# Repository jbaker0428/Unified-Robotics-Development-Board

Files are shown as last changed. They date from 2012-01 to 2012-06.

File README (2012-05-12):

The Unified Robotics Development Board seeks to provide an extensible open-hardware platform for robotics development based on XMOS technology.

SOFTWARE USED:
PCB design: Eagle 5.6.0
STM32 code: Eclipse Indigo SR1 (CDT) and YAGARTO (Yet another GNU ARM toolchain)
XMOS code: XMOS Development Environment

The Unified Robotics Development Board is licensed under a Creative Commons Attribution-NonCommercial-ShareAlike 3.0 Unported License.

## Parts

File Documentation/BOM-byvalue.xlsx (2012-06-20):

Part | Value | Device | Package | Vendor | Vendor PN | Manufacturer PN | Qty | Unit Price @ Qty | Part Price | TOTAL: | Notes
BAT1 |  | CBC3112 | D7C-VFN20 | DK | 859-1010-1-ND | CBC3112-D7C-TR1 | 1 | 2.91 | 2.91 | 191.4278
C1, C76, C102, C103 | 1uF | C-US0402 | C0402 | DK | 445-4979-1-ND | C1005X5R1C105M | 4 | 0.27 | 1.08
C2, C9, C10, C17, C29, C35, C74, C75, C92, C98, C99, C105, C106 | 10uF | C-USC0805 | C0805 | DK | 490-5523-1-ND | GRM21BR61E106KA73L | 13 | 0.231 | 3.003
C3, C4, C11, C12, C13, C14, C21, C22, C23, C25, C28, C30, C33, C38, C39, C40, C41, C42, C45, C46, C47. C49, C55, C56, C86, C87, C88, C89 | 0.1uF | C-USC0603 | C0603 | DK | 311-1343-1-ND | CC0603ZRY5V9BB104 | 29 | 0.017 | 0.493
C5, C6 | 18pF | C-USC0603 | C0603 |  |  |  | 2 |  | 0
C7 | 290pF | C-USC0603 | C0603 | DK | 445-5066-1-ND | C1608C0G1H301J | 1 | 0.12 | 0.12 |  | Real part value is 300pF
C8 | 100uF | C-USC0805 | C0805 |  |  |  | 1 |  | 0 |  | TODO: Make this a 1206
C15, C52 | 22uF | CAP_ | AXIAL-5MM | DK | 445-2904-ND | FK22Y5V1E226Z | 2 | 1.4 | 2.8
C16 | 4.7uF | CAP_ | AXIAL-5MM | DK | 445-2880-ND | FK26Y5V1E475Z | 1 | 0.43 | 0.43
C18 | 0.01uF | C-USC0603 | C0603 | DK | 478-1227-1-ND | 06035C103KAT2A | 1 | 0.06 | 0.06 |  | 0.01uF = 10k pF
C19, C24 | 4.7uF | C-USC0805 | C0805 | DK | 490-3335-1-ND | GRM21BR61E475KA12L | 2 | 0.39 | 0.78
C20 | 0.22uF | C-USC0603 | C0603 | DK | 445-5191-1-ND | C1608X7R1E224K | 1 | 0.28 | 0.28
C26 | 10nF | C-USC0603 | C0603 | DK | 478-1227-1-ND | 06035C103KAT2A | 1 | 0.06 | 0.06 |  | 10nF = 10k pF (redundant line item)
C31, C43, C95 | 33nF | C-USC0603 | C0603 | DK | 445-5106-1-ND | C1608X7R1E333K | 3 | 0.16 | 0.48 |  | 33nF = 33k pF = 0.033uF
C32, C44 | 500uF | CPOL-USE2.5-6 | E2,5-6 |  |  |  | 2 |  | 0
C34 | 0.068uF | CAP_ | AXIAL-5MM | DK | 445-5257-ND | FK28X7R1H683K | 1 | 0.35 | 0.35
C36 | 152uF | C-USC0805 | C0805 |  |  |  | 1 |  | 0
C37 | 220uF | CPOL-USD | PANASONIC_D |  |  |  | 1 |  | 0
C50 | 0.018uF | CAP_ | AXIAL-5MM | DK | 445-5253-ND | FK28X7R1H153K | 1 | 0.29 | 0.29 |  | Real part value is 0.015uF
C51 | 68pF | CAP_ | AXIAL-5MM | DK | 1292PH-ND | S680K29SL0N63J5R | 1 | 0.24 | 0.24
C53 | DNP | CAP_ | AXIAL-5MM |  |  |  | 1 |  | 0
C54 | 1000pF | C-USC0603 | C0603 | DK | 445-1308-1-ND | C1608X7R1H102K | 1 | 0.1 | 0.1
C57 | 4.7nF | C-USC0603 | C0603 | DK | 445-1310-1-ND | C1608X7R1H472K | 1 | 0.1 | 0.1
C48, C58, C59, C60, C61, C62, C63, C64, C65, C66, C67, C90, C91, C93, C94, C101, C104, C107, C108, C114, C115, C116, C117, C118 | 0.1uF | C-US0402 | C0402 | DK | 445-7384-1-ND | C1005X5R1V104K | 22 | 0.09 | 1.98
C69 | 8.2pF | C-USC0603 | C0603 | DK | 445-5045-1-ND | C1608C0G1H8R2D | 1 | 0.12 | 0.12
D1, D2, D3, D4, D5, D6, D7, D8, D9, D10, D11, D12, D13, D14, D15, D16, D17, D18, D19, D20, D21, D22, D23, D24, D26, D27 |  | RB751 | SOD523 | ME | 771-RB751S40,115 | RB751S40,115 | 26 | 0.033 | 0.858
D25 | SCHOTTKY-3 | VF30100S | TO220ABS | DK | VF30100S-E3/4WGI-ND | VF30100S-E3/4W | 1 | 1.59 | 1.59
D29, D30, D31, D32, D33, D34, D35 | SCHOTTKY | PMEG3030EP | SOD128 | Avnet | PMEG3030EP,115/BKN | PMEG3030EP,115 | 8 | 0.149 | 1.192
D36 | 18.8V SO | TVS | DO-201 | ME | 576-1.5KE16CA | 1.5KE16CA
F1 | 1.5A | PTCPTH | PTC | Future | RUEF160 | RUEF160 | 1 | 0.2904 | 0.2904 |  | Ihold of 1.60A
F2 | 6A | PTCPTH | PTC | Future | RUEF600 | RUEF600 | 1 | 0.484 | 0.484
F3 | 3A | PTCPTH | PTC | Future | RUEF300 | RUEF300 | 1 | 0.3025 | 0.3025
IC1, IC2 | VNH2SP30 | VNH2SP30 | MULTIPOWERSO-30 | Nu Horizons | VNH2SP30TR-E | VNH2SP30TR-E | 2 | 9.2236 | 18.4472
IC3 | L298N | L298N | MULTIWATT-15 | Future | L298N | L298N | 1 | 3.33 | 3.33
IC4, IC5 | 741G3157DCKR | SN74LVC1G3157 | SC-70-6 | Newark | 32H6365 | SN74LVC1G3157DCKR | 2 | 0.378 | 0.756
IC6 | 1K | 93-C46B | SOT23-6 | microchipDIRECT | 93C46BT-I/OT | 93C46BT-I/OT | 1 | 0.17 | 0.17
IC7 | 74164DHVQFN14 | 74164DHVQFN14 | DHVQFN14 | ME | 771-74HC164BQ115 | 74HC164BQ,115 | 1 | 0.48 | 0.48
IC8 |  | LV8549M | LSOP-10 | ME | 863-LV8549M-TLM-H | LV8549M-TLM-H | 1 | 2.28 | 2.28
IC9 |  | 742G17DCK | DCK_R-PDSO-G6 | ME | 595-SN74AUP2G17DCKR | SN74AUP2G17DCKR | 1 | 0.47 | 0.47
J1 | ESPM02200 | ESPM02200 | ESPM02200 | DK | 523-ESPM02200 | ESPM02200 | 1 | 1.47 | 1.47
J2, J3, J4, J5 | 796689-2 | 796689-2 | 796689-2 | DK | A98442-ND | 796689-2 | 4 | 0.89 | 3.56
J6 |  | RJ45 | RJ45-8-PTH | DK | S9399-ND | SMJ102-S88I-DS-11 | 1 | 2.89 | 2.89
JARD- 8 pin headers | ARDUINO_SHIELDNO_SILK | ARDUINO_SHIELDNO_SILK | DUEMILANOVE_VIAS | SFE | PRT-09279 |  | 2 | 0.5 | 1
JARD - 6 pin headers | ARDUINO_SHIELDNO_SILK | ARDUINO_SHIELDNO_SILK | DUEMILANOVE_VIAS | SFE | PRT-09280 |  | 2 | 0.5 | 1
JP1 |  | PINHD-2X10 | 2X10 Right angle | DK | S9180-ND | SBH11-PBPC-D10-RA-BK | 1 | 0.98 | 0.98
JP3, JP4, JP5 |  | PINHD-2X6 Female | 2X06 Right angle | DK | S5559-ND | PPPC062LJBN-RC | 3 | 1.55 | 4.65
JP6, JP7, JP8, JP9, JP10, JP11, JP12, JP14, JP15, JP16, JP17, JP18, JP19 |  | M03PTH | 1X03 | DK | S7001-ND | PPTC031LFBN-RC | 13 | 0.441 | 5.733
JP13 |  | M05X2SHD | 2X5-SHROUDED | DK | WM3478-ND | 702461004 | 1 | 1.64 | 1.64
JP20, JP21 |  | M02PTH | 1X02 | DK | XG8T-0231-ND | XG8T-0231 | 2 | 0.13 | 0.26
JP23 |  | PINHD-2X8 | 2X08 | ME | 649-68602-116HLF | 68602-116HLF | 1 | 0.3 | 0.3
JP2 |  | PINHD-2X11 | 2X11 Female | DK | S7079-ND | PPTC112LFBN-RC | 1 | 1.58 | 1.58
JP22 |  | PINHD-2X5 | 2X05 Female | DK | 609-3573-ND | 68683-305LF | 1 | 1.38 | 1.38
JP24, JP25, JP26, JP27 |  | M05PTH (M05) | 1X05 | DK | 609-4303-ND | 68002-205HLF | 3 | 0.27 | 0.81
JP28 |  | M04PTH | 1X04 Female | Future | PPTC041LFBN-RC | PPTC041LFBN-RC | 1 | 0.4961 | 0.4961
L1 | 68uH | L-USSLF12565 | SLF12565 | DK | 445-3849-1-ND | SLF12565T-680M2R0-H | 1 | 1.88 | 1.88
L2 | 4.7uH | L-US0207/5V | 0207/5V | DK | DN7773-ND | 4590R-472K | 1 | 2.85 | 2.85
L3 | 3.3uH | L-USPANASONIC_ELL6 | PANASONIC_ELL6 | ME | 667-ELL-6SH3R3M | ELL-6SH3R3M | 1 | 0.8 | 0.8
L4 | 15uH | L-USIHLP-3232DZ | IHLP-3232DZ | DK | 541-1347-1-ND | IHLP3232DZER150M11 | 1 | 1.74 | 1.74
L5 | Ferrite Bead |  | 402 | DK | 587-2088-1-ND | BKP1005HS221-T | 1 | 0.3 | 0.3
LED1, LED2, LED3, LED4, LED5, LED6, LED7 | Green 2mA | LEDCHIPLED_0603 | CHIPLED_0603 | DK | 475-2709-1-ND | LG L29K-G2J1-24-Z | 7 | 0.22 | 1.54
LED8 | Amber 10mA | LEDCHIPLED_0603 | CHIPLED_0603 | DK | P11464CT-ND | LNJ414K8YRA | 1 | 0.45 | 0.45 |  | Cheaper on ME, but not stocked
Q1, Q3 | NCH | MOSFET-NCHANNELSMD | SOT23-3 | DK | 785-1011-1-ND | AO3416 | 2 | 0.55 | 1.1
Q2 | NCH | IPP80N04S3-06 | TO-220 | DK | IPP80N04S3-06-ND | IPP80N04S3-06 | 1 | 1.22 | 1.22
Q15 | IRLML2402 | MOSFET-NCHANNELSMD | SOT23-3 | ME | 942-IRLML2402GTRPBF | IRLML2402GTRPBF | 1 | 0.41 | 0.41
Q16 | IRLML6402 | MOSFET-PCHANNELSMD | SOT23-3 | ME | 942-IRLML6402TRPBF | IRLML6402TRPBF | 1 | 0.57 | 0.57
R1 | 2R2 | R-US_R0603 | R0603 | DK | P2.2GCT-ND | ERJ-3GEYJ2R2V | 1 | 0.02 | 0.02
R3 | 2.2M | R-US_R0603 | R0603 | DK | P2.20MHCT-ND | ERJ-3EKF2204V | 1 | 0.04 | 0.04
R23 | 470 | R-US_R0603 | R0603 | DK | P470HCT-ND | ERJ-3EKF4700V | 1 | 0.04 | 0.04
R5, R16, R22, R77, R114 | 1.5K | R-US_R0402 | R0402 | DK | RMCF0402FT1K50CT-ND | RMCF0402FT1K50 | 5 | 0.04 | 0.2
R2, R8, R30, R34, R35, R76, R106, R108, R109, R118, R122, R123, R124, R125, R147, R150 | 10K | R-US_R0603 | R0603 | DK | P10.0KHCT-ND | ERJ-3EKF1002V | 5 | 0.04 | 0.2
R6, R7, R17, R18 | 10 | R-US_R0402 | R0402 | DK | P10.0LCT-ND | ERJ-2RKF10R0X | 4 | 0.06 | 0.24
R9, R13, R14, R19, R32, R97 | 100K | R-US_R0402 | R0402 | DK | P100KJCT-ND | ERJ-2GEJ104X | 6 | 0.05 | 0.3
R11, R12 | 4.7K | R-US_R0402 | R0402 | DK | P4.7KJCT-ND | ERJ-2GEJ472X | 2 | 0.05 | 0.1
R20, R21 | 27 | R-US_R0402 | R0402 | DK | P27.0LCT-ND | ERJ-2RKF27R0X | 2 | 0.06 | 0.12
R24, R25, R26, R27, R28, R33, R91, R92, R93, R94 | 33 | R-US_R0402 | R0402 | Newark | 64R5276 | ERJ-2RKF33R0X | 10 | 0.009 | 0.09
R29 | 2.2K | R-US_R0402 | R0402 | DK | P2.20KLCT-ND | ERJ-2RKF2201X | 1 | 0.06 | 0.06
R34, R36 | 100K | R-US_R0603 | R0603 | DK | P100KHCT-ND | ERJ-3EKF1003V | 2 | 0.04 | 0.08
R15, R65, R66, R67, R68, R100, R101, R102, R103, R104, R105 | 100 | R-US_R0402 | R0402 | ME | 6667-ERJ-2GEJ101X | ERJ-2GEJ101X | 11 | 0.07 | 0.77
R31 | 1M | R-US_R0603 | R0603 | DK | P1.00MHCT-ND | ERJ-3EKF1004V | 1 | 0.04 | 0.04
R37 | 1.96K | R-US_0207/5V | 0207/5V | DK | RNF14FTD1K96CT-ND | RNF14FTD1K96 | 1 | 0.15 | 0.15
R35, R78 | 0.5 | R-US_R0805 | R0805 | DK | RL12S.50FCT-ND | RL1220S-R50-F | 2 | 0.35 | 0.7
R38 | 221K | R-US_0207/5V | 0207/5V | DK | RNF14FTD221KCT-ND | RNF14FTD221K | 1 | 0.15 | 0.15
R4, R8, R39 | 4.7K | R-US_R0603 | R0603 | DK | P4.70KHCT-ND | ERJ-3EKF4701V | 3 | 0.04 | 0.12
R41, R42, R43, R44, R45, R46, R47, R48, R49, R50, R51, R52, R53, R54, R55, R56, R57, R58, R59, R60, R61, R62, R63, R64 | 200 | R-US_R0402 | R0402 | ME | 667-ERJ-2GEJ201X | ERJ-2GEJ201X | 24 | 0.07 | 1.68
R10, R69, R70, R71, R72, R75, R95, R110, R111, R112, R113, R117, R142, R143 | 1K | R-US_R0603 | R0603 | Newark | 64R5308 | ERJ-3EKF1001V | 14 | 0.007 | 0.098
R73, R74, R115, R116 | 3.3K | R-US_R0603 | R0603 | ME | 667-ERJ-3EKF3301V | ERJ-3EKF3301V | 4 | 0.07 | 0.28
R79, R80, R120, R121 | 2.7K | R-US_R0603 | R0603 | Newark | 64R5334 | ERJ-3EKF2701V | 4 | 0.007 | 0.028
R81 | 11K | R-US_R0603 | R0603 | ME | 667-ERJ-3EKF1102V | ERJ-3EKF1102V | 1 | 0.07 | 0.07
R82 | 18K | R-US_R0603 | R0603 | Avnet | ERJ-3EKF1802V | ERJ-3EKF1802V | 1 | 0.0048 | 0.0048
R83 | 0.3 | R-US_R0402 | R0402 | DK | P.30AKCT-ND | ERJ-2BQFR30X | 1 | 0.59 | 0.59
R84 | 1.8K | R-US_R0603 | R0603 | ME | 667-ERJ-3EKF1801V | ERJ-3EKF1801V | 1 | 0.07 | 0.07
R85 | 6.8K | R-US_R0603 | R0603 | DK | P6.80KHCT-ND | ERJ-3EKF6801V | 1 | 0.1 | 0.1
R86 | 2.32K 1% | R-US_R0402 | R0402 | DK | P2.32KLCT-ND | ERJ-2RKF2321X | 1 | 0.1 | 0.1
R87, R88, R89, R90 | 49R9 1% | R-US_R0402 | R0402 | DK | P49.9LCT-ND | ERJ-2RKF49R9X | 4 | 0.1 | 0.4
R96 | 330 | R-US_R0603 | R0603 | DK | P330GCT-ND | ERJ-3GEYJ331V | 1 | 0.1 | 0.1
R107 | 3.24K | R-US_R0603 | R0603 | DK | P3.24KHCT-ND | ERJ-3EKF3241V | 1 | 0.1 | 0.1
R139 | 2.2K | R-US_R0603 | R0603 | DK | RHM2.2KDCT-ND | ESR03EZPJ222 | 1 | 0.17 | 0.17
R140 | 2K | R-US_R0603 | R0603 | DK | RHM2.0KDCT-ND | ESR03EZPJ202 | 1 | 0.17 | 0.17
R141 | 2.4K | R-US_R0603 | R0603 | DK | P2.4KGCT-ND | ERJ-3GEYJ242V | 1 | 0.1 | 0.1
R144 | 47K | R-US_R0402 | R0402 | ME | 667-ERJ-2GEJ473X | ERJ-2GEJ473X | 1 | 0.07 | 0.07
R145 | 41.2K | R-US_0207/5V | 0207/5V | DK | RNF14FTD41K2CT-ND | RNF14FTD41K2 | 1 | 0.15 | 0.15
R146 | 66.5K | R-US_0207/5V | 0207/5V | DK | RNF14FTD66K5CT-ND | RNF14FTD66K5 | 1 | 0.15 | 0.15
R148 | 330K | R-US_R0603 | R0603 | Newark | 64R5341 | ERJ-3EKF3303V | 1 | 0.007 | 0.007
R149 | 39K | R-US_R0603 | R0603 | ME | 667-ERJ-3EKF3902V | ERJ-3EKF3902V | 1 | 0.07 | 0.07
U1, U2 | XS2-L2-124QFN | XS2-L2-124QFN | TQFN-124 | DK | 880-1004-ND | XS1-L02A-QF124-C4 | 2 | 15.1 | 30.2
U3 | STM32L15XVX | STM32L15XVX | LQFP100 | Future | STM32L151V8T6 | STM32L151V8T6 | 1 | 3.4848 | 3.4848
U4 | SST25VF010A | 25LC080SN | SO-08 | DK | SST25VF010A-33-4I-SAE-ND | SST25VF010A-33-4I-SAE | 1 | 0.79 | 0.79
U5 | NCP303LSN09 | NCP303LSN09 | SOT23-5 | ME | 863-NCP303LSN09T1G | NCP303LSN09T1G | 1 | 0.45 | 0.45
U6 | NC7WZ07 | NC7WZ07 | SC70-6 | DK | NC7WZ07P6XCT-ND | NC7WZ07P6X | 1 | 0.47 | 0.47
U7 | MC34063SMD | MC34063SMD | SO08 | ME | 511-MC34063EBD-TR | MC34063EBD-TR | 1 | 0.47 | 0.47
U8 | TPS54620 | TPS54620 | S-PVQFN-N14 | Avnet | TPS54620RGYR | TPS54620RGYR | 1 | 4.17 | 4.17
U9 | FAN2012 | FAN2012 | MLP6 | ME | 512-FAN2012MPXCT | FAN2012MPXCT | 1 | 1.23 | 1.23
U10 | TPS5431 | TPS5431 | R-PDSO-G08 | Avnet | TPS5431DDA | TPS5431DDA | 1 | 3.09 | 3.09
U11 | TXS0102 | TXS0102 | DCT-R-PDSO-G8 | ME | 595-TXS0102DCTR | TXS0102DCTR | 1 | 1.08 | 1.08
U12, U19, U20, U21, U22 | TXB0108 | TXB0108 | DQS_R-PUSON-N20 | Avnet | TXB0108DQSR/BKN | TXB0108DQSR | 5 | 1.33 | 6.65
U13 | HMC5883LSMD | HMC5883LSMD | 16LPCC | Newark | 20T0699 | HMC5883L-TR | 1 | 1.62 | 1.62
U14 | MMA845XQ | MMA845XQ | VQFN-16 | DK | MMA8452QT-ND | MMA8452QT | 1 | 1.49 | 1.49
U15 | L3GD20 | L3GD20 | LGA16-4X4 | DK | 497-12081-1-ND | L3GD20TR | 1 | 8.26 | 8.26
U16 | AMIS-39101 | AMIS-39101 | SO-28W | DK | 766-1004-1-ND | AMIS39101PNPB4RG | 1 | 6.66 | 6.66
U17 | CDCLVC1103 | CDCLVC1103 | PW_R-PDSO-G08 | DK | 296-27587-1-ND | CDCLVC1103PWR | 1 | 3.02 | 3.02
U18 |  | FT2232D | PQFP48 | DK | 768-1010-1-ND | FT2232D-REEL | 1 | 6.99 | 6.99
U23 | STM32F103C8T6 | STM32F103C8T6 | TQFP48 | Arrow | STM32F103C8T6 | STM32F103C8T6 | 1 | 3.56 | 3.56
U24 |  | ENC28J60 | QFN28-ML_6X6MM | microchipDIRECT | ENC28J60-I/ML | ENC28J60-I/ML | 1 | 2.03 | 2.03
X1, X4, X5 | MINI-USB-UX60-MB-5S8 | MINI-USB-UX60-MB-5S8 | UX60-MB-5S8 | ME | 798-UX60-MB-5S8 | MUSB-05-X-D-SM-A | 3 | 1.26 | 3.78
X2 | USD-SOCKETNEW | USD-SOCKETNEW | MICRO-SD-SOCKET-PP | ME | 798-DM3AT-SF-PEJM5 | DM3AT-SF-PEJM5 | 1 | 2.6 | 2.6
X3 | XBEE-1 | XBEE-PTH | XBEE-PTH | SFE | PRT-08272 |  | 2 | 0.95 | 1.9
Y1 | 20M | ASFL1 | ASF | DK | 535-10816-1-ND | ASFL1-20.000MHZ-L-T | 1 | 1.99 | 1.99
Y2 | 6M | CSTCR6M00G53 | CSTCR6M | DK | 490-1204-1-ND | CSTCR6M00G53-R0 | 1 | 0.58 | 0.58

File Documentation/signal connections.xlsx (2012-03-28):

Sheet: XMOS Dualchip
Xcore Signal | U1 Package Pin | X0 Port | X0 Signal |  | U1 Package Pin | X1 Port | X1 Signal | U2 Package Pin | X2 Port | X2 Signal |  | U2 Package Pin | X3 Port | X3 Signal
D00 | A15 | P1A | SPI_MISO |  | A39 | P1A |  | A15 | P1A |  |  | A39 | P1A | SDA
D01 | A16 | P1B | EEPROM_SS |  | A40 | P1B |  | A16 | P1B |  |  | A40 | P1B | SCL
D02 | A5 | P4A0 |  |  | A41 | P4A0 | ETH_OSC1 | A5 | P16A0 | SERVO_2 |  | A41 | P4A0 | U15_INT1
D03 | A6 | P4A1 |  |  | A42 |  |  | A6 | P16A1 | SERVO_3 |  | A42 | P4A1 | U15_INT2
D04 | A7 | P4B0 | XLA1o |  | A43 | P4B0 | ETH_!INT | A7 | P16A2 | SERVO_4 |  | A43 | P4B0 | ENC4_A
D05 | A8 | P4B1 | XLA0o |  | A44 |  |  | A8 | P16A3 | SERVO_5 |  | A44 | P4B1 | ENC4_B
D06 | A9 | P4B2 | XLA0i |  | A45 |  |  | A9 | P16A4 | IC1_PWM |  | A45 | P4B2 | ENC4_Z
D07 | A10 | P4B3 | XLA1i |  | A46 |  |  | A10 | P16A5 | IC2_PWM |  | A46 | P4B3
D08 | A11 | P4A2 |  |  | A47 |  |  | A11 | P16A6 | IC3_PWM |  | A47 | P4A2 | U14_INT2
D09 | A12 | P4A3 |  |  | A48 |  |  | A12 | P16A7 |  |  | A48 | P4A3 | U14_INT1
D10 | A13 | P1C | SPI_SCK |  | A49 | P1C |  | A13 | P1C |  |  | A49 | P1C | XBEE_DOUT
D11 | A14 | P1D | SPI_MOSI |  | A50 | P1D |  | A14 | P1D |  |  | A50 | P1D | XBEE_DIN
D12 | A55 | P1E | JP3_9 |  | A21 | P1E | UEXT_SDA | A55 | P1E | STM32 U1_TX | RX in XMOS library | A21 | P1E | IC7_CLR
D13 | A57 | P1F | JP3_7 |  | A23 | P1F | UEXT_RXD | A57 | P1F | JP5_10 |  | A23 | P1F
D14 | A58 | P4C0 |  |  | A24 | P4C0 |  | A58 | P4C0 |  |  | A24 | P4C0 | ENC2_A
D15 | A59 | P4C1 |  |  | A25 | P4C1 |  | A59 | P4C1 |  |  | A25 | P4C1 | ENC2_B
D16 | A60 | XLB1o |  | U2_XLB1i | A26 | XLB1o |  | A60 | XLB1o |  |  | A26 | P4D0 | ENC3_A
D17 | A61 | XLB0o |  | U2_XLB0i | A27 | XLB0o |  | A61 | XLB0o |  |  | A27 | P4D1 | ENC3_B
D18 | A63 | XLB0i |  | U2_XLB0o | A29 | XLB0i |  | A63 | XLB0i |  |  | A29 | P4D2 | ENC3_Z
D19 | A64 | XLB1i |  | U2_XLB1o | A30 | XLB1i |  | A64 | XLB1i |  |  | A30 | P4D3
D20 | A65 | P4C2 |  |  | A31 | P4C2 |  | A65 | P16A14 | SERVO_0 |  | A31 | P4C2 | ENC2_Z
D21 | A66 | P4C3 |  |  | A32 | P4C3 |  | A66 | P16A15 | SERVO_1 |  | A32 | P4C3
D22 | A56 | P1G | JP3_8 |  | A22 | P1G | UEXT_TXD | A56 | P1G | STM32_TIM3_CH2 |  | A22 | P1G | IC7_CLK
D23 | A62 | P1H | XSYS_UART_TX | RX in XMOS library | A28 | P1H | JP4_10 | A62 | P1H |  |  | A28 | P1H
D24 | A54 | P1I | JP3_10 |  | A20 | P1I | UEXT_SCL | A54 | P1I | STM32 U1_RX |  | A20 | P1I | IC7_DATA
D25 | A67 | P1J | XSYS_UART_RX | TX in XMOS library | A33 | P1J | JP4_3 | A67 | P1J | JP5_3 |  | A33 | P1J | U13_DRDY
D26 | B38 | P4E0 |  |  | B16 |  |  | B38 |  |  |  | B16 | P4E0 | IC1_DIAGB
D27 | B39 | P4E1 |  |  | B17 |  |  | B39 |  |  |  | B17 | P4E1 | IC1_DIAGA
D28 | B40 | P4F0 |  |  | B18 |  |  | B40 |  |  |  | B18 | P4F0 | ENC1_A
D29 | B41 | P4F1 |  |  | B19 |  |  | B41 |  |  |  | B19 | P4F1 | ENC1_B
D30 | B44 | P4F2 |  |  | B20 |  |  | B44 |  |  |  | B20 | P4F2 | ENC1_Z
D31 | B45 | P4F3 |  |  | B21 |  |  | B45 |  |  |  | B21 | P4E2 | IC2_DIAGB
D32 | B46 | P4E2 |  |  | B22 |  |  | B46 |  |  |  | B22 | P4E3 | IC2_DIAGA
D33 | B47 | P4E3 |  |  | B23 |  |  | B47 |  |  |  | B23
D34 | A4 | P1K | uSD_SS |  | B24 | P1K | JP4_9 | A4 | P1K | JP5_1 |  | B24 | P1K
D35 | A3 | P1L | UEXT_SS |  | B25 | P1L | JP4_8 | A3 | P1L | JP5_2 |  | B25 | P1L | IC8_IN2
D36 | B48 | P1M | JP3_4 |  | B26 | P1M | JP4_7 | B48 | P1M | JP5_9 |  | B26 | P1M | IC8_IN1
D37 | B49 | P1N | JP3_3 |  | B27 | P1N | JP4_4 | B49 | P1N | JP5_8 |  | B27 | P1N | IC8_ENA
D38 | B50 | P10 | JP3_2 |  | B30 | P10 | JP4_2 | B50 | P10 | JP5_7 |  | B30 | P10 | XBEE_CTS
D39 | B51 | P1P | JP3_1 |  | B31 | P1P | JP4_1 | B51 | P1P | JP5_4 |  | B31 | P1P | XBEE_RTS
D40 | B52 | P8D4 |  |  |  |  |  | B52
D41 | B53 | P8D5 |  |  |  |  |  | B53
D42 | B54 | P8D6 |  |  |  |  |  | B54
D43 | B55 | P8D7 |  |  |  |  |  | B55

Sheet: XMOS Dualchip Planning
Block | 1-bit ports |  | Chip | Core | Block | X0 1-bit | X1 1-bit | X2 1-bit | X3 1-bit | Unallocated
Pmod 0 | 8 |  | U1 |  | Pmod 0 | 8
Pmod 1 | 8 |  | U1 |  | Pmod 1 |  | 8
Pmod 2 | 8 |  | U2 |  | Pmod 2 |  |  | 8
SPI | 6 |  | U1 |  | SPI | 6
I2C | 3 | and a P4 |  |  | IMU I2C |  |  |  | 3
UEXT I2C | 2 |  |  |  | UEXT I2C |  | 2
PWM | 0 |  | U2 |  | PWM |  |  | 0
Enc | 9 |  | U2 |  | Enc |  |  |  | 9
STM32 UART | 3 |  |  |  | STM32 UART |  |  | 3
Xbee UART | 4 | Include RTS/CTS |  |  | Xbee UART |  |  |  | 4
UEXT UART | 2 |  |  |  | UEXT UART |  | 2
XSYS UART | 2 |  |  |  | XSYS UART | 2
 | 55
 |  |  |  |  | Total 1-bits | 16 | 12 | 11 | 16 | 0
 |  |  |  |  | 1-bit ports remaining | 0 | 4 | 5 | 0
By Block ^
 |  |  |  |  | By Core^
VNH2SP30 DIAG | P4E
Encoder 1 | P4F
Encoder 2 | P4C
Encoder 3 | P4D
Encoder 4 | P4B
IMU ints | P4A
U13 DRDY
VNH2SP30 inputs | IC7
L298N inputs | IC7

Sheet: STM32 Connections
Signal | Pin | IO Pin | Description
ADCIN 0 |  |  | Arduino ADC 0
ADCIN 1 |  |  | Arduino ADC 1
ADCIN 2
ADCIN 3
ADCIN 4 |  |  | DAC0
ADCIN 5 |  |  | DAC1
ADCIN 6 |  |  | Arduino ADC 2
ADCIN 7 |  |  | Arduino ADC 3
ADCIN 8 |  |  | Arduino ADC 4
ADCIN 9 |  |  | LN298 CSB
ADCIN 10 |  |  | External ADC 0
ADCIN 11 |  |  | External ADC 1
ADCIN 12 |  |  | External ADC 2
ADCIN 13 |  |  | External ADC 3
ADCIN 14 |  | PC4 | Digital
ADCIN 15 |  |  | Arduino ADC 5
ADCIN 16 |  |  | Internal temperature sensor
ADCIN 17
ADCIN 18 |  | PB12 | Digital
ADCIN 19 |  | PB13 | Digital
ADCIN 20 |  | PB14 | Digital
ADCIN 21 |  | PB15 | Digital
ADCIN 22 |  |  | Motor 0
ADCIN 23 |  |  | Motor 1
ADCIN 24 |  |  | LN298 CSA
ADCIN 25 |  |  | Supply voltage monitor
Timer outputs
TIM10_CH1 | 51 | PB12 | Arduino 3
TIM9_CH1 | 52 | PB13, PD0 | Arduino 5 OR Arduino 10
TIM9_CH2 | 53 | PB14 | Arduino 6
TIM11_CH1 | 54 | PB15 | Arduino 11
TIM4_CH1 | 59 | PD12 | Arduino 9
TIM4_CH2 | 60 | PD13
TIM4_CH3 | 61 | PD14
TIM4_CH4 | 62 | PD15
TIM3_CH1 | 63 | PC6
TIM3_CH2 | 64 | PC7
TIM3_CH3 | 65 | PC8
TIM3_CH4 | 66 | PC9
TIM3_CH2 | 91 | PB5 | XMOS UART Clock Input
TIM3_CH1 | 2 | PE3

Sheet: Arduino Connections
Arduino Pin | Arduino Signal | STM32 Pin | STM32 Signal | Function
0 |  | 55 | PD9 | RX
1 |  | 56 | PD8 | TX
2 |  |  | PD14
3 |  |  | PB12
4 |  |  | PD13
5 |  |  | PB13
6 |  |  | PB14
7 |  |  | PD10
8 |  |  | PD11
9 |  |  | PD12
10 |  |  | PD0 | SPI SS
11 |  |  | PB15 | SPI MOSI
12 |  |  | PD3 | SPI MISO
13 |  |  | PD1 | SPI SCK
14 |  |  | 3.3V | Aref
15 |  |  | PA0 | Analog 0
16 |  |  | PA1 | Analog 1
17 |  |  | PA6 | Analog 2
18 |  |  | PA7 | Analog 3
19 |  |  | PB0/PC4 | Analog 4
20 |  |  | PB1/PC4 | Analog 5
21 |  |  | PC15
22 |  |  | PC14
23 |  |  | PE6
24 |  |  | PE5
25 |  |  | PE4
26 |  |  | PE3
27 |  |  | PE2
28 |  |  | PE1
29 |  |  | PE0
30 |  |  | PA4 | DAC 1
31 |  |  | PA5 | DAC 2
32 |  |  | PD7
33 |  |  | PD6 | U2_RX
34 |  |  | PD5 | U2_TX
35 |  |  | PC12
36 |  |  | PC11
37 |  |  | PC10
38 |  |  | PC9

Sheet: I2C
Device | Description | Max Frequency | Bus Capacitance
HMC5883L | Compass | 400 kHz
MMA8452Q | Accelerometer | 4.5 MHz

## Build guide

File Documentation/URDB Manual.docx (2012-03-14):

## Servo Power Block

Power is supplied to the servo connections by a TPS54620 switching regulator. By default, this regulator is configured to output 6V. RC servos use a variety of supply voltages, generally from 4.4V to 8V, with some larger servos operating off of as much as 12V. Changing the output voltage of the TPS54620 requires changing the value of many of the passive components in the regulator circuit. For ease of soldering, the relevant components are through-hole parts instead of the smaller 0603/0805 surface mount packages used elsewhere on the board. To calculate the correct component values for a desired output voltage, Texas Instruments provides a utility called SwitcherPro. Create a new design in SwitcherPro using the TPS54620 and set the inputs as shown below, changing the Vout value as desired.

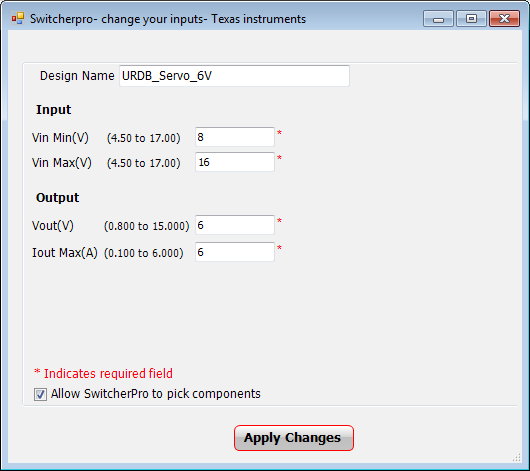
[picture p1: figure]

Note: Do not use the exact parts recommended by SwitcherPro, as they are not the correct package sizes. The pads are sized for vertically-mounted 1/4W PTH resistors, ceramic capacitors with 5mm spacing, and vertically-mounted axial inductors. Values for common output voltages are shown below.

Table X: Servo power block component values
Component (SwitcherPro) | Component (URDB label) | VO = 4.4V | VO = 6V | VO = 8V | VO = 12V
R1 | R146 | 45.3K | 66.5K | 90.9K | 140K
R2 | R147 | 10K | 10K | 10K | 10K
R3 | R37 | 2.15K | 1.96K | 2.26K | 2.26K
R4 | R36 | 100K | 100K | 100K | 100K
R5 | R38 | 205K | 221K | 243K | 287K
R6 | R145 | 53.6K | 41.2K | 33.2K | 26.1K
C1 | Not Available | Open | Open | Open | Open
C2 | C52 | Open | Open | Open | Open
C3 | C51 | 100uF | 22uF | 22uF | 22uF
C4 | C50 | 0.018uF | 0.018uF | 0.018uF | 0.018uF
C5 | C16 | 4.7uF | 4.7uF | 4.7uF | 4.7uF
C6 | C34 | 0.022uF | 0.068uF | 0.047uF | 8200pF
C7 | C51 | 560pF | 68pF | 68pF | 390pF
C8 | C15 | 22uF | 22uF | 22uF | 22uF
L1 | L2 | 3.9uH | 4.7uH | 4.7uH | 3.3uH

## XMOS-STM32 Communication Link

A device initiates communication by sending an opcode with the CMD/REPLY flag set to 0. The receiving device acknowledges the command by sending a reply with the same opcode. After the ACK byte is sent, both devices begin the transfer of data associated with the opcode. In the event of an opcode being added in the future calling for both devices to send data, these transfers can occur simultaneously. Neither device shall initiate a new command until the current exchange is completed.

### I/O Pin Message Data Format

Opcodes 35 and 36 pertain to the I/O pins connected to the Arduino headers of the STM32 coprocessor. All functionality of these STM32 I/O pins is exposed to the XMOS. When sending a GET_IO_PIN request, only the first 6 bits (the Arduino pin ID) need to be sent. When sending a GET_IO_PIN reply or a SET_IO_PIN request, the full 3-byte data packet must be sent.

23 | 22 | 21 | 20 | 19 | 18 | 17 | 16 | 16
Must be 0 | | | | | | | Value | AF[3]

15 | 14 | 13 | 12 | 11 | 10 | 9 | 8 | 7 | 6 | 5 | 4 | 3 | 2 | 1 | 0
AF [2:0] | | | PU/PD[1:0] | | Speed[1:0] | | Type | Mode[1:0] | | Pin ID[5:0]

Bits 23:18: | Reserved, must be set to 0.
Bit 17: | Pin value If Mode = 00: Pin’s IDR value. If Mode = 01: Pin’s ODR value. If Mode = 10 or 11: 0.
Bits 16:13 | Pin alternate function Pin’s alternate function register (AFRL or AFRH) value.
Bits 12:11 | Pin pull-up/pull-down configuration Pin’s PUPDR value.
Bits 10:9 | Pin output speed Pin’s OSPEEDR value.
Bit 8: | Pin type Pin’s OTYPER value.
Bits 7:6 | Pin mode Pin’s MODER value.
Bits 5:0 | Pin Arduino ID Numeric designation of the pin on the Arduino silkscreen.

## XMOS Threads

The base URDB firmware executes six concurrent threads during device operation.. This leaves 24 free threads for application code.

Table X: XMOS threads
Thread | Core
IMU I²C Server | 3
SPI Server | 0
STM32 UART Server | 2
PWM Module | 2
Navigation Service | 3
XMOS JTAG USB UART | 0

In addition to the base firmware threads, the following core assignments are required when using the Pmod and UEXT expansion headers. Note: Every I/O pin on these ports is an XMOS 1-bit port. While the hardware is configured with these expansion header formats in mind, they can be used as independent 1-bit ports by threads running on the same core if desired.

Table X: Expansion header threads
Thread | Core
Pmod A | 0
Pmod B | 1
Pmod C | 2
UEXT I²C Server | 1
UEXT UART Server | 1

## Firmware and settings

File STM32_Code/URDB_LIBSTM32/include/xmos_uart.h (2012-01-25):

/*
 * xmos_uart.h
 *
 *  Created on: Nov 28, 2011
 *      Author: Joe
 */

#ifndef XMOS_UART_H_
#define XMOS_UART_H_

short int cmd_data_bits[41];	// Index of array = opcode, Data in array = # of bytes of data for that opcode
short int reply_data_bits[41];
uint8_t cmd_data_bytes[41];
uint8_t reply_data_bytes[41];

uint8_t received_control_byte, command;

#define USART1_DR_ADDRESS		USART1->DR		// TODO: verify this is the correct thing to point to

#define XMOS_TX_PORT			GPIOB
#define XMOS_TX_PIN				GPIO_Pin_6
#define XMOS_TX_SRC				GPIO_PinSource6
#define XMOS_TX_DMA_CHANNEL		DMA1_Channel4
#define XMOS_TX_DMA_FLAG_TC		DMA1_FLAG_TC4
#define XMOS_TX_DMA_FLAG_GL		DMA1_FLAG_GL4

#define XMOS_RX_PORT			GPIOB
#define XMOS_RX_PIN				GPIO_Pin_7
#define XMOS_RX_SRC				GPIO_PinSource7
#define XMOS_RX_DMA_CHANNEL		DMA1_Channel5
#define XMOS_RX_DMA_FLAG_TC		DMA1_FLAG_TC5
#define XMOS_RX_DMA_FLAG_GL		DMA1_FLAG_GL5

#define DMA1_CLK				RCC_AHBPeriph_DMA1
/*
 * 			-------- COMMUNICATIONS FORMAT --------
 *
 * 		-----------------------------
 * 		| CMD/REPLY | OPCODE | DATA |
 * 		-----------------------------
 *
 * Where:
 * - CMD/REPLY is a 1-bit value. 0 = command, 1 = reply (ACK).
 *
 * - OPCODE is a 7-bit value from the defined values below.
 *
 * - DATA is the data associated with the command. Data width varies depending
 * 		on the OPCODE and CMD/REPLY values (see command table below). Note that
 * 		all data is sent in 8-bit chunks, the width values below denote what of
 * 		that is actual data vs garbage.
 *
 * 	  A device initiates communication by sending an opcode with the CMD/REPLY
 * 	flag set to 0. The receiving devices acknowledges the command by sending a
 * 	reply with the same opcode. After the ACK byte is sent, both devices begin
 * 	the transfer of data associated with the opcode. In the event of an opcode
 * 	being added in the future calling for both devices to send data, these
 * 	transfers can occur simultaenously. Neither device shall initiate a new
 * 	command until the current exchange is completed.
 *
 *	  The STM32 should set up DMA channels, buffers, etc. BEFORE sending the ACK
 *	reply byte, as the speed of the link and higher processing speed of the XMOS
 *	does not allow for time to do so after the ACK reply byte is sent.
 *
 */

// Command formatting "register"
#define CMD_CMD				0 << 7
#define CMD_REPLY			1 << 7	// 0 = command, 1 = reply
#define CMD_OPCODE_6		1 << 6
#define CMD_OPCODE_5		1 << 5
#define CMD_OPCODE_4		1 << 4
#define CMD_OPCODE_3		1 << 3
#define CMD_OPCODE_2		1 << 2
#define CMD_OPCODE_1		1 << 1
#define CMD_OPCODE_0		1

/** @defgroup UART_opcodes
  * @{
  */
// 		Command				Opcode	Command data width	Reply data width
#define CMD_GET_ADC_0		0		// 0				current_adc_res
#define CMD_GET_ADC_1		1		// 0				current_adc_res
#define CMD_GET_ADC_2		2		// 0				current_adc_res
#define CMD_GET_ADC_3		3		// 0				current_adc_res
#define CMD_GET_ADC_4		4		// 0				current_adc_res
#define CMD_GET_ADC_5		5		// 0				current_adc_res
#define CMD_GET_ADC_6		6		// 0				current_adc_res
#define CMD_GET_ADC_7		7		// 0				current_adc_res
#define CMD_GET_ADC_8		8		// 0				current_adc_res
#define CMD_GET_ADC_9		9		// 0				current_adc_res
#define CMD_GET_ADC_10		10		// 0				current_adc_res
#define CMD_GET_ADC_11		11		// 0				current_adc_res
#define CMD_GET_ADC_12		12		// 0				current_adc_res
#define CMD_GET_ADC_13		13		// 0				current_adc_res
#define CMD_GET_ADC_14		14		// 0				current_adc_res
#define CMD_GET_ADC_15		15		// 0				current_adc_res
#define CMD_GET_ADC_16		16		// 0				current_adc_res
#define CMD_GET_ADC_17		17		// 0				current_adc_res
#define CMD_GET_ADC_18		18		// 0				current_adc_res
#define CMD_GET_ADC_19		19		// 0				current_adc_res
#define CMD_GET_ADC_20		20		// 0				current_adc_res
#define CMD_GET_ADC_21		21		// 0				current_adc_res
#define CMD_GET_ADC_22		22		// 0				current_adc_res
#define CMD_GET_ADC_23		23		// 0				current_adc_res
#define CMD_GET_ADC_RES		24		// 0				2-bit
#define CMD_SET_ADC_RES		25		// 2-bit			0
#define CMD_USB_SEND		26		// 8-bit ?			0
#define CMD_GET_RTC_TIME	27		// 0				24-bit
#define CMD_GET_RTC_DATE	28		// 0				24-bit
#define CMD_SET_RTC_TIME	29		// 24-bit			0
#define CMD_SET_RTC_DATE	30		// 24-bit			0
#define CMD_GET_DAC_RES		31		// 0				1-bit
#define CMD_SET_DAC_RES		32		// 1-bit			0
#define CMD_GET_IO_PIN		35		// 6-bit			18-bit
#define CMD_SET_IO_PIN		36		// 18-bit			0
#define CMD_GET_U16_PIN		37		// 3-bit			1-bit
#define CMD_SET_U16_PIN		38		// 4-bit			0
#define CMD_GET_U16_ALL		39		// 0				8-bit
#define CMD_SET_U16_ALL		40		// 8-bit			0
/**
  * @}
  */

/**
 * Populate the <cmd/reply>_data_widths[] arrays
 */
void set_data_widths(void);

/**
 * Initializes TIM3_CH2 to output a 32MHz clock to the XMOS.
 */
void uart_clk_out_init(void);

/**
 * Initializes the TX/RX pins for UART1.
 */
void uart_gpio_init(void);

/**
 * Initializes channels 4 and 5 of DMA1 for UART1 TX/RX.
 */
void uart_dma_init(void);

/**
 * Initializes USART1 to URDB spec.
 */
void xmos_uart_init(void);

/**
 * Activates USART1 RX DMA channel to wait for a command code from the XMOS.
 * This is the default state when there is nothing to send and no transaction in progress.
 */
void uart_idle(void);

/**
 * Initiates a new transaction with the XMOS.
 * @param opcode Command code to send which is some value of @ref UART_opcodes
 * @param tx_data Data to transmit
 * @return 0 if success, -1 if a transaction is already in progress
 */
int uart_initiate_transaction(uint8_t opcode, int tx_data);

/**
 * Handles reply data from a master-mode transaction
 * @param opcode Initiating command code which is some value of @ref UART_opcodes
 */
void uart_handle_reply_data(uint8_t opcode);

/**
 * Handle commands sent by the XMOS.
 * This should be called from an RX interrupt breaks the idle state.
 * @param opcode Received command code which is some value of @ref UART_opcodes
 */
void uart_handle_command(uint8_t opcode);

/**
 * Enable the UART transmitter in DMA mode
 * @param base_adr Value to be used in DMA_InitType.DMA_MemoryBaseAddr
 * @param num_bytes Number of bytes to transmit (DMA_InitType.DMA_BufferSize)
 */
void uart_tx_enable(uint32_t base_addr, int num_bytes);

/**
 * Disable UART transmitter's DMA channel
 */
void uart_tx_disable(void);

/**
 * Enable the UART receiver in DMA mode
 * @param base_adr Value to be used in DMA_InitType.DMA_MemoryBaseAddr
 * @param num_bytes Number of bytes to receive (DMA_InitType.DMA_BufferSize)
 */
void uart_rx_enable(uint32_t base_addr, int num_bytes);

/**
 * Disable UART receiver's DMA channel
 */
void uart_rx_disable(void);

#endif /* XMOS_UART_H_ */

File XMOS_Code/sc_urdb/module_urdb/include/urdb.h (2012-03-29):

/**
 *	@file urdb.h
 *
 *	@date 11/9/2011
 *	@author jbaker
 */

#ifndef URDB_H_
#define URDB_H_

#include <xs1.h>
#include <platform.h>
#include <print.h>
#include <stdlib.h>
#include <syscall.h>
#include <stdio.h>
#include <xccompat.h>

// Cores for essential URDB threads

#define ETHERNET_CORE	1
#define IMU_I2C_CORE	3
#define SPI_CORE		0
#define STM32_CORE		2
#define XBEE_CORE		3
#define XTAG_UART_CORE	0
/**
 * @def PWM_CORE
 * Sets which core the PWM thread is to be run on.
 */
#define PWM_CORE		2
/**
 * @def NAVIGATION_CORE
 * Sets which core the navigation service is to be run on.
 * This service should poll the IMU, read encoders, etc.
 */
#define NAVIGATION_CORE	3

// Cores for other peripheral hardware

#define	PMOD_A_CORE		0
#define	PMOD_B_CORE		1
#define PMOD_C_CORE		2
#define UEXT_I2C_CORE	1
#define UEXT_UART_CORE	1


/**
 * @var imu_i2c_req_ch Resource ID for the I2C IO server request input chanend
 * @var imu_i2c_service_ch Resource ID for the I2C IO server request servicing chanend
 * @var spi_req_ch Resource ID for the SPI IO server request input chanend
 * @var spi_service_ch Resource ID for the SPI IO server request servicing chanend
 * @var stm32_req_ch Resource ID for the STM32 UART IO server request input chanend
 * @var stm32_service_ch Resource ID for the STM32 UART IO server request servicing chanend
 * @var pwm_chanend Resource ID for the PWM thread input chanend
 * @var navigation_chanend Resource ID for the navigation thread input chanend
 */
unsigned imu_eth_req_ch;
unsigned imu_eth_service_ch;
unsigned imu_i2c_req_ch;
unsigned imu_i2c_service_ch;
unsigned spi_req_ch;
unsigned spi_service_ch;
unsigned stm32_req_ch;
unsigned stm32_service_ch;
unsigned pwm_chanend;
unsigned navigation_chanend;
unsigned uext_i2c_req_ch;
unsigned uext_i2c_service_ch;
unsigned uext_uart_req_ch;
unsigned uext_uart_service_ch;
unsigned xbee_req_ch;
unsigned xbee_service_ch;
unsigned xtag_uart_req_ch;
unsigned xtag_uart_service_ch;



on stdcore[IMU_I2C_CORE] : struct r_i2c imu_i2c = { PORT_IMU_SCL, PORT_IMU_SDA };
// TODO: struct i2c_data_info i2c_data1; <--- in I2C server thread or here?
on stdcore[IMU_I2C_CORE] : in buffered port imu_interrupts = PORT_IMU_INTS;
on stdcore[IMU_I2C_CORE] : in buffered port compass_drdy = PORT_COMPASS_DRDY;
on stdcore[NAVIGATION_CORE] : in port encoder1 = PORT_QEI1;
on stdcore[NAVIGATION_CORE] : in port encoder2 = PORT_QEI2;
on stdcore[NAVIGATION_CORE] : in port encoder3 = PORT_QEI3;
on stdcore[NAVIGATION_CORE] : in port encoder4 = PORT_QEI4;

on stdcore[NAVIGATION_CORE] : in buffered port hbridge_diags = PORT_HBRIDGE_DIAGS;
on stdcore[NAVIGATION_CORE] : out port motordir_clr = PORT_MOTORDIR_CLR;
on stdcore[NAVIGATION_CORE] : out port motordir_clk = PORT_MOTORDIR_CLK;
on stdcore[NAVIGATION_CORE] : out port motordir_data = PORT_MOTORDIR_DATA;

on stdcore[NAVIGATION_CORE] : out port stepper_en = PORT_STEPPER_EN;
on stdcore[NAVIGATION_CORE] : out port stepper_in1= PORT_STEPPER_IN1;
on stdcore[NAVIGATION_CORE] : out port stepper_in2 = PORT_STEPPER_IN2;

on stdcore[NAVIGATION_CORE] : out port hbridge_modes = PORT_HBRIDGE_INPUTS;
on stdcore[PWM_CORE] : out buffered port:32 pwm_port = PORT_PWM;
on stdcore[STM32_CORE]: in	port stm32_clk = PORT_STM32_CLK;
on stdcore[STM32_CORE]: out buffered port:8 stm32_tx = PORT_STM32_TX;
on stdcore[STM32_CORE]: in	buffered port:8 stm32_rx = PORT_STM32_RX;
on stdcore[STM32_CORE]: clock stm32_uart_clk = XS1_CLKBLK_5;
on stdcore[UEXT_I2C_CORE] : struct r_i2c uext_i2c = { PORT_UEXT_SCL, PORT_UEXT_SDA };
on stdcore[UEXT_UART_CORE]: out	buffered port:8 uext_tx = PORT_UEXT_UART_TX;
on stdcore[UEXT_UART_CORE]: in	buffered port:8 uext_rx = PORT_UEXT_UART_RX;
on stdcore[XBEE_CORE]: out	buffered port:8 xbee_tx = PORT_XBEE_TX;
on stdcore[XBEE_CORE]: in	buffered port:8 xbee_rx = PORT_XBEE_RX;
on stdcore[XBEE_CORE]: out	port xbee_rts = PORT_XBEE_RTS;
on stdcore[XBEE_CORE]: in	buffered port xbee_cts = PORT_XBEE_CTS;
on stdcore[XTAG_UART_CORE]: out	buffered port:8 xtag_tx = PORT_USB_TX;
on stdcore[XTAG_UART_CORE]: in	buffered port:8 xtag_rx = PORT_USB_RX;

clock ref0;
clock ref1;

/**
 * @fn void urdb_init(void)
 * @brief Runs all threads related to the URDB firmware.
 *
 * The urdb_init function starts execution of all URDB firmware threads.
 * Before beginning thread execution, the chanend resources for the IO servers are allocated
 * and their resource IDs are saved to global vars.
 *
 * @param xbee_mode Boolean argument to run the XBEE UART I/O server. Pass one of the XBEE_MODE macros from io_servers.h.
 *
 */
void urdb_init(unsigned char xbee_mode);


#endif /* URDB_H_ */

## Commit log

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2011-10-11 In working on the Arduino IO pins: Moved the STM32 down slightly. Changed the SPI2 MOSI line to a different IO pin that also has a timer output for PWM.
    [urdevboard.brd, urdevboard.sch]
2011-10-11 Changed the STM32 ground routing to be multiple vias. This fixes some 3v3_2 plane breaks.
    [urdevboard.brd, urdevboard.sch]
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2011-10-11 IO expander circuit done. Pin assignments for the first motor driver are not finalized.
    [urdevboard.brd, urdevboard.sch]
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2011-10-16 Circuit for MC34063A switching regulator made. Still need to confirm values for 5V and 3.3V versions and capacitor materials.
    [urdevboard.brd, urdevboard.sch]
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2011-10-18 Traces laid out for new 3.3V regulator. Started intra-circuit traces for sensors and tweaked their positions.
    [urdevboard.brd, urdevboard.sch]
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2011-10-21 Ripped up traces to U1 pending replacement with L2 model.
    [urdevboard.brd, urdevboard.sch]
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2011-10-21 IO pins on new U1 all named. Added a missing pullup resistor to U1 debug pin.
    [urdevboard.brd, urdevboard.sch]
2011-10-22 Pmod IO connections added to schematic -- they had to be reversed to avert via cthulu.
    [urdevboard.brd, urdevboard.sch]
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2011-10-23 RST_N escape issue (Issue #7) fixed.
    [urdevboard.brd]
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2011-10-27 Swapped positions of U1 power and config blocks to fit more decoupling caps.
    [urdevboard.sch]
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2011-10-27 Tweaked some traces around U2 to fix some 3.3V plane breaks and extended the plane to the right edge of the board.
    [urdevboard.brd]
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2011-10-29 Fixed R107 name/value swap.
    [urdevboard.brd, urdevboard.sch]
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2011-10-29 Fixed L4 to use larger inductor with correct current rating.
    [urdevboard.brd, urdevboard.sch]
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2011-11-03 +3V3 plane fix south of U2.
    [urdevboard.brd]
2011-11-03 Another +3V3 plane break fixed on the Arduino +3.3V pin.
    [urdevboard.brd]
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2011-11-03 Added a fat +3V3 trace under the 1.0V regulator to reinforce the power plane.
    [urdevboard.brd]
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2011-11-10 Committing whatever small changes happened prior to the repository fix.
    [urdevboard.brd]
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2011-11-11 Big shuffling of the XMOS serial interfaces...
    STM32_U1_RX moved to X0D12 (X0P1E).
    STM32_U1_TX moved to X0D22 (X0P1G).
    STM32_TIM3_CH2 (PB5) connected to X0D13 (X0P1F) for a 32MHz clock input to the XMOS for UART clocking.
    U13_SA0 turns out to just be an address input. Disconnected from XMOS and connected to +3V3.
    U13_INT1 moved to X1D10 (X1P1C) and U13_INT2 moved to X1D11 (X1P1D). This gets the U13 interrupt pins onto the I2C core, resolving that part of Issue #2.
    uSD_SS assigned to X1D34 (X1P1K).
    [signal connections.xlsx, urdevboard.brd, urdevboard.sch]
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2011-11-11 Fixed 1.0V trace width on north side of U1.
    [urdevboard.brd]
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2011-11-17 Swapped get/set positions for RTC for consistency.
    [XMOS-STM32-UART.xlsx]
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2011-11-20 Fixed L4 and C37 overlapping.
    [urdevboard.brd]
2011-11-20 Added schematic elements for second H-bridge with correct net names.
    [urdevboard.brd, urdevboard.sch]
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2011-11-21 Replaced J1 with a model capable of handling 60A of current.
    [urdevboard.brd, urdevboard.sch]
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2011-11-21 Minor alterations to IC1 resistor traces to fix power plane to IC5.
    [urdevboard.brd]
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2011-11-22 Forgot a couple of IC2 traces on the last commit -- fixed now.
    [urdevboard.brd]
2011-11-22 Fixed C31 being on a silkscreen label.
    [urdevboard.brd]
2011-11-22 Fixed R5-R7 being on a silkscreen label.
    [urdevboard.brd]
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2011-11-22 Moved the whole Raduino block 100 mils to the left to fix the silkscreen overlap with X1.
    [urdevboard.brd]
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2011-11-22 Oops, IC5 interrupt pins were backwards. Fixed.
    [signal connections.xlsx, urdevboard.brd, urdevboard.sch]
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2011-11-25 Resolved the U14 SS pin location issue.
    Nuke-from-orbit fix: U14 moved to the I2C bus because it supports both.
    [signal connections.xlsx, urdevboard.brd, urdevboard.sch]
2011-11-25 Fixed unfinished change to SERVO_4 and SERVO_5 assignments in schematic.
    [urdevboard.brd, urdevboard.sch]
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2011-11-25 Added missing level shifters to IC5 interrupts.
    [urdevboard.brd, urdevboard.sch]
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2011-11-25 Fixed clearance error on JP7.
    [urdevboard.brd, urdevboard.sch]
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2011-11-28 Makefile/project fixed. UART code started.
    [urdb_stm32.h, xmos_uart.c, xmos_uart.h]
2011-11-28 Un-including core_cm3.h for now, it's causing problems.
    core_cm3.h appears to need to include stm32l1xx.h, which it was not. However, stm32l1xx.h includes core_cm3.h and going both ways current causes many errors.
    [urdb_stm32.h]
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2011-12-03 XMOS power-on reset circuit.
    [urdevboard.brd, urdevboard.sch]
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2011-12-04 Fixed one missing bit on 1.0V bus.
    [urdevboard.brd]
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2011-12-04 Fixed comment typo.
    "Reply data with" -> "Reply data width"
    [stm32.h, xmos_uart.h]
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2011-12-04 Added second set of data width arrays to track by bytes.
    This will use a bunch of extra memory up front, but will save on a lot of arithmetic that there won't be time for.
    [xmos_uart.c, xmos_uart.h]
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2011-12-05 Fixed a couple of minor plane breaks.
    [urdevboard.brd]
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2011-12-05 Replaced second potentiometer with a normal resistor.
    The right way to do this is to have Rbias (R145 in this case) remain constant and calculate R1 across the output voltage range.
    [urdevboard.brd, urdevboard.sch]
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2011-12-09 Added missing trace to 5V_REG pin on VCC regulator.
    [urdevboard.brd]
2011-12-09 Added vias to second VCC regulator ground plane and fixed overlap with U6_VIN plane.
    [urdevboard.brd]
2011-12-10 Committing minor changes before yet another U6 swap.
    [urdevboard.brd]
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2011-12-16 Converted the majority of the U6 circuit to PTH components and replaced the potentiometer with a resistor.
    An adjustable buck regulator requires too many components of variable value.
    This approach abandons the fault-prone on-the-fly potentiometer-based output in favor of fixed-value components which the user can easily swap out.
    [urdevboard.brd, urdevboard.sch]
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2011-12-16 Replaced a pair of GND traces in the 1.0V regulator circuit with a small plane.
    [urdevboard.brd, urdevboard.sch]
2011-12-16 Fixed DRC clearance error on U6 planes.
    [urdevboard.brd, urdevboard.sch]
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2011-12-20 Removed the OSHW logo, as the -NC Creative Commons license does not fit the OSHW definition.
    [urdevboard.brd]
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2011-12-28 Added missing IC3_VCC trace between R135 and C48.
    [urdevboard.brd]
2011-12-28 Fixed a small airwire under U6.
    [urdevboard.brd]
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2012-01-01 Fixed outdated references to the servo thread being on core 0.
    [Threads.xlsx]
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2012-01-01 Fixed pwmSingleBitPort passing servo_chanend instead of pwm_chanend.
2012-01-01 Fixed SPI core assignment.
    [Threads.xlsx]
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2012-01-04 Fixed missing JP4_3 resistor trace.
    Ratsnest: Nothing to do!
    [urdevboard.brd]
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2012-01-05 Deleted urdevboard.bom.
    That file was the output from the wrong BOM ULP in Eagle.
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2012-01-07 Swapped out J1 for a cheaper part.
    [BOM-byvalue.xlsx, urdevboard.brd, urdevboard.sch]
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2012-01-09 Added missing GND symbol to U15 decoupling caps.
    [urdevboard.brd, urdevboard.sch]
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2012-01-11 Fixed a pair of via drills that were missed in the 8 mil change.
    [urdevboard.brd]
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2012-01-13 Added 4 new opcodes to control U15 from the XMOS.
    The data_widths arrays in the STM32 library also had not been updated with the additon of opcodes 35 and 36. That has been resolved.
    [XMOS-STM32-UART.xlsx]
2012-01-13 Fixed client_fifo_t definition and prototypes.
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2012-01-13 A couple of more missed ground vias for the 15 mil drill change.
    [urdevboard.brd]
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2012-01-13 Replaced the new IO headers and the DAC headers with a single 2x10 part.
    [BOM-byvalue.xlsx, urdevboard.brd, urdevboard.sch]
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2012-01-14 Reran the STM32 NRSTIN JTAG trace to avoid problems with JP24 traces.
    [urdevboard.brd]
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2012-01-14 Arduino analog pins 4 and 5 mode switcher redesigned.
    The N/P MOSFET pairs (Q15 and Q16) would not have functioned correctly in a reverse voltage/current condition.
    They have been replaced with 2:1 mux/demux ICs (IC4 and IC5) which are a much better fit for the configuration.
    Q31 and Q32 have been renamed to Q15 and Q16 respectively to remove the gap in Q__ part names.
    [BOM-byvalue.xlsx, urdevboard.brd, urdevboard.sch]
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2012-01-18 Added missing STM32 signals to Arduino connections tab.
    [signal connections.xlsx]
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2012-01-23 Tightened up the leftmost group of traces on JP24.
    [urdevboard.brd]
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2012-01-23 Shifted U7_FB trace to the right a bit.
    As-is, the trace was running over bottom layer signal traces in the same direction. This was going to be a problem soon when connecting the Xbee.
    [urdevboard.brd]
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2012-01-24 Made JP25 a 2x6 header.
    There are 13 signals that can justify a breakout header connection, but going up to a 2x7 is going to be a space problem.
    One of the 13 signals will be left unconnected.
    [urdevboard.brd, urdevboard.sch]
2012-01-24 Tightened up the ADC connection traces a bit more to make space for JP25 signals.
    [urdevboard.brd, urdevboard.sch]
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2012-01-24 Fixed XBee chanend declaration.
    [urdb.h]
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2012-01-25 Deleted old crystal circuit (will be replaced with an oscillator chip).
    C4-C6
    R3-R4
    U3
    Y1
    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
    [urdevboard.brd, urdevboard.sch]
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2012-01-25 Added new 20MHz oscillator circuit (Y1 and C100).
    [urdevboard.brd, urdevboard.sch]
2012-01-25 Ripped up signal traces coming out of the reset circuit and EEPROM.
    Both of these circuits will likely have their position adjusted slightly.
    [urdevboard.brd, urdevboard.sch]
2012-01-25 EEPROM, Gadgeteer, and reset circuit position adjustments.
    This should leave enough space above the Gadgeteer for U3 and U4.
    [urdevboard.brd]
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2012-01-25 Swapped the positions of the input stage of the 1.0V regulator and R61-R64.
    The way they were positioned only made sense in the context of the XS1-L2's VDDIO pins and the 3.3V plane.
    [urdevboard.brd]
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2012-01-26 DRU change: minimum via drill = 10 mil.
    Drill/conductor spacing requirements reduced to what is allowed by 4PCB and Sierra Circuits.
    This spacing change means that the increased via drill/annular ring size is not causing clearance errors.
    [urdevboard.brd, urdevboard.sch]
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2012-01-28 Redesigned Gadgeteer logic translation circuitry.
    The old pullup/FET setup has been removed in favor of logic translator ICs.
    U3_P1A (assuming no changed to the U3 assignments) will be used to select I2C/non-I2C operation modes for the Gadgeteer socket.
    Set U3_P1A high for I2C operation. This controls the select input of the IC6 and IC7 multiplexers, as well as the enable inputs of the translators (U17's enable input is inverted via IC8).
    [BOM-byvalue.xlsx, urdevboard.brd, urdevboard.sch]
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2012-01-28 U17 Bx side traces broken out.
    [urdevboard.brd, urdevboard.sch]
2012-01-28 U17 ground pad vias added.
    Also fixed some of the U6_PH copper not being renamed to U10_PH.
    [urdevboard.brd]
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2012-01-29 Fixed a 3.3V plane break going into U18/C101.
    [urdevboard.brd]
2012-01-29 JP3 silk labels fixed.
    The odd-side pin number labels were overlapping the header silkscreen.
    [urdevboard.brd]
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2012-01-29 U3-U5 bus voltage reversal fixed.
    3.3V goes to VDDIO, 1.0V goes to VDD.
    Recently placed U3 decoupling caps have been rearranged accordingly.
    [urdevboard.brd, urdevboard.sch]
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2012-01-31 C86 and C94 added.
    Also added missing silkscreen label for C93.
    [urdevboard.brd]
2012-01-31 C87 placed.
    Also added missing C92 ground via.
    [urdevboard.brd]
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2012-01-31 North side 5V trace width reduced to 32 mil max.
    The 40 mil trace is no longer needed since the 1.0V regulator move.
    [urdevboard.brd]
2012-01-31 Tightened spacing of JP4-JP8.
    The space along the edge of the board will be used
    to route XTAG signals to U4.
    [urdevboard.brd]
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2012-01-31 IC3 traces redone.
    R128 and R133 swapped positions to fit the PWM resistor where it belongs.
    [urdevboard.brd]
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2012-02-10 Improved spacing on recently placed parallel diagonal traces.
    The tighter spacing technically passes DRC, but it's closer than it needs to be.
    [urdevboard.brd]
2012-02-10 Adjusted a few STM32 traces to reduce potential coupling issues.
    [urdevboard.brd]
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2012-02-10 Fixed U2_PLL_AVDD net name.
    [urdevboard.brd, urdevboard.sch]
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2012-02-10 Fixed U8 copper pour signals.
    [urdevboard.brd, urdevboard.sch]
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2012-02-10 Moved the Gadgeteer block off-board for now.
    Leaving it on the board was restricting repositioning planning too much.
    It might end up closer to the XBee.
    [urdevboard.brd]
2012-02-10 Replaced the H-bridge logic translators with the DQS variant.
    -The TXB0108DQS is a smaller QFN without the heat slug.
    -Sourced from Mouser.
    [BOM-byvalue.xlsx, urdevboard.brd, urdevboard.sch]
2012-02-10 Ripped up logic translator traces for the H-bridges.
    Those traces were no longer relevant, as they were designed to line
    up with an XMOS chip on the A side that is no longer there.
    [urdevboard.brd]
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2012-02-17 Fixed a minor plane beak on the STM32 PE0/PE1 traces.
    [urdevboard.brd]
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2012-02-17 Removed pins 12 and 16 of the XBee from JP25.
    -Pin 12 is CTS, 16 is RTS. These will be connected to an XMOS.
    -JP25 has been shortened from 2x6 pins to 2x5.
    -The JP25 ends of the remaining 10 JP25 signals have been ripped up,
    as it will be moved shortly to make use of extra space from the Arduino move.
    [BOM-byvalue.xlsx, urdevboard.brd, urdevboard.sch]
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2012-02-18 Fixed DRC clearance error on X3 P1K-P1N escape traces.
    [urdevboard.brd]
2012-02-19 Fixed U1/U2 quantity, it was only listed as one.
    That's a very important $15 difference to account for...
    [BOM-byvalue.xlsx]
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2012-02-20 Tweaked the 5V bus trace layer change location near the U11 5V trace.
    This will give the 3.3V plane a bit more space to prevent breaks
    after the IMU block is placed.
    [urdevboard.brd]
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2012-02-20 Gadgeteer requires 8 ports, not 7.
    The 8th port is the I2C mode switch.
    If need be, this IO line could be replaced with a jumper.
    [signal connections.xlsx]
2012-02-21 Revised the Gadgeteer level shifter circuit.
    -U17 must always be enabled because the Gadgeteer spec calls for
    two GPIO pins on a type-I socket. U17_OE tied to +3V3.
    -The U17_OE inverter (IC8) has been deleted.
    -Two more 74LVC1G3157 mux/demux chips (IC8 and IC9) added
    to the B-side of the translator. This isolates the B-side I2C
    signals (JP13_8 and JP13_9) between U17 and U18.
    -Swapped U17 for the smaller QFN variant used on the rest of the board.
    -This block might get one more pass to swap U18 for the QFN variant,
    which has a different pinout. This may allow the I2C circuit to be
    compacted further.
    [BOM-byvalue.xlsx, urdevboard.brd, urdevboard.sch]
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2012-02-21 IMU traces escaped out from U2 slightly further.
    The end of the escape traces now corresponds to the shortest airwire
    for all IMU signals.
    [urdevboard.brd]
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2012-02-25 Fixed DRU angle error on SCL line.
    [urdevboard.brd]
2012-02-25 H-bridge logic translation space optimization: step one.
    Replaced all of the resistors in the H-bridge logic circuits with 0402 variants.
    This allows for all of the resistors to be placed in one horizontal row.
    [urdevboard.brd, urdevboard.sch]
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2012-02-25 Adjusted the R117_IC2 net trace to fix a minor ground plane break.
    [urdevboard.brd]
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2012-02-26 Rotated the U1 and U2 blocks 90 degrees clockwise.
    This will make the H-bridge/I2C traces to U2 use much less space,
    as many more of them are now facing the correct direction.
    The same applies to the XTAG signals.
    [urdevboard.brd]
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2012-02-27 Replaced the Gadgeteer block with an Olimex UEXT connector.
    The Gadgeteer specification calls for 3.3V-level I/O. However,
    all of the I/O pins must be 3.6V tolerant minimum. Thus, the logic
    level translation scheme implemented would not have worked correctly.
    By contrast, the UEXT is a pure-3.3V specification with no second 5V supply.
    -The I2C and UART pins of the UEXT will be their own serial busses, independent
    of the I2C bus used for the IMU and the STM32/XBee UARTs.
    -The UEXT SPI bus will connect to the existing XMOS SPI bus, only adding another
    slave select line.
    -Only 5 1-bit ports are required to the Gadgeteer's 7.
    [BOM-byvalue.xlsx, signal connections.xlsx, urdevboard.brd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]
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2012-02-29 JP23 output capacitors moved to top of board.
    -All U16 block capacitors (C57 to C67) changed to a 0402 package.
    -The polarity on JP23 was reversed to make this change possible
    with cleaner routing of outputs from U16.
    [BOM-byvalue.xlsx, urdevboard.brd, urdevboard.sch]
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2012-02-29 Tightened the H-bridge output traces a bit.
    [urdevboard.brd]
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2012-02-29 Reset circuit power vias.
    [urdevboard.brd]
2012-02-29 Moved the Pmod header diodes to the top side of the board.
    In order to make this fit, JP6-JP8 were finally replaced with the
    SparkFun.lbr component with non-long pads. The BOM line items have
    been consolidated.
    [BOM-byvalue.xlsx, urdevboard.brd, urdevboard.sch]
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2012-03-01 Revised XBee RTS/CTS escaping from U2.
    These signals were coming out on the wrong side of the IMU traces.
    [urdevboard.brd]
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2012-03-04 Rotated C4 to escape XBee DIN/DOUT signals in the correct direction.
    [urdevboard.brd]
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2012-03-04 Fixed U15 INT breakout trace positioning.
    [urdevboard.brd]
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2012-03-05 Tied H-bridges directly to the 12V plane.
    -With properly sized vias and the internal/external 12V planes,
    it is no longer necessary to limit the drivers to less than their
    maximum rated current.
    -The output traces have been replaced with a pair of polygons (top and bottom).
    -IC3 output net names have been corrected.
    -Fuses and LEDs for all three drivers have been removed.
    [BOM-byvalue.xlsx, urdevboard.brd, urdevboard.sch]
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2012-03-05 Replaced clock fanout buffer with a 1:2 input:output model.
    [BOM-byvalue.xlsx, urdevboard.brd, urdevboard.sch]
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2012-03-05 U2 DEBUG_N trace breakout.
    This would be such a big problem on 2 layers...
    [urdevboard.brd]
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2012-03-05 Tightened up the STM32 UART traces to avoid passing under the XBee.
    [urdevboard.brd]
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2012-03-09 Reversed positioning of U2_CLK and DEBUG_N traces.
    [urdevboard.brd]
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2012-03-09 Tightened up JP13 escape traces.
    [urdevboard.brd]
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2012-03-09 Ran a 1.0V trace that will go to the reset circuit.
    [urdevboard.brd]
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2012-03-09 Cleaned up a few obsolete trace layer changes to the right of U3.
    These were leftovers that were missed in the 4-layer branch.
    [urdevboard.brd]
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2012-03-11 Fixed Reset signal name on Arduino shield.
    [urdevboard.brd, urdevboard.sch]
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2012-03-11 U23 passives in tight positioning.
    [urdevboard.brd]
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2012-03-12 Moved U3 down 150 mils and right 150 mils.
    Not all traces have been reconnected with this commit, but
    DRC errors have been cleaned up.
    [urdevboard.brd]
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2012-03-12 Moved the JP9-JP12 ADC headers right 250 mils and up 10 mils.
    That little bit of vertical placement fudging with the 10 mil grid
    should prevent JP12 from being obstructed by Arduino shields.
    [urdevboard.brd]
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2012-03-12 Reverting the addition of the NCP699 regulator.
    The FTDI debugger like the XDK uses is a much better option than
    an XS-1 based XTAG. It's a single QFP48 chip that costs as much as the
    XS1-64QFP would have cost alone.
    [BOM-byvalue.xlsx, urdevboard.brd, urdevboard.sch]
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2012-03-12 Tightened up servo PWM/microSD traces a bit.
    [urdevboard.brd]
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2012-03-12 Reset circuit placed on-board.
    [BOM-byvalue.xlsx, urdevboard.brd, urdevboard.sch]
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2012-03-12 Fixed font on debugger silkscreen labels.
    [urdevboard.brd]
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2012-03-14 Shifted U1 left-side 1.0V trace to bottom layer under the package.
    This was quickly going to become an issue with escape routing on that side of U1.
    [urdevboard.brd]
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2012-03-14 Fixed microSD power via position.
    Moving X2 lower and lower accidentally moved the power via out
    from above the 3.3V plane.
    [urdevboard.brd]
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2012-03-14 Pulled PC13 off of JP24 and replaced it with PD7.
    This frees up PC13 for its one and only alternate function: RTC_AF1.
    [signal connections.xlsx, urdevboard.brd, urdevboard.sch]
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2012-03-15 Fixed a whole slew of non-blind ground vias.
    Was about to make the STM32 VDD plane when I caught on to these vias.
    [urdevboard.brd, urdevboard.sch]
2012-03-16 Added thin-film backup battery for RTC.
    This replaces the coin cell design previously considered.
    Still need to convert the STM32 to the VDD supply symbol and add a plane for VDD.
    [BOM-byvalue.xlsx, urdevboard.brd, urdevboard.sch]
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2012-03-16 EMI improvements.
    -Lots of minor trace spacing increases.
    -Added a few guard traces where appropriate.
    -Added a board-edge guard ring, but the loop is broken by the USB ports having a Restrict area.
    Not sure how much this will hinder guard ring performance. Might be better to do it on the bottom layer.
    [urdevboard.brd]
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2012-03-17 Fixed silkscreen label positioning for Arduino analog input 0.
    [urdevboard.brd]
2012-03-17 Board-wide reverse voltage protection at the J1 terminal.
    -This circuit is based on the reverse polarity protection suggested in the
    VNH2SP30 data sheet. Said circuit has been removed from the H-bridge driver
    circuits, as it would now be redundant. This has resulted in a significant
    decrease in the board space taken up by the driver circuits.
    -The new circuit has not yet been placed on-board. This will be done alongside
    changes to the third motor driver in the near future.
    [BOM-byvalue.xlsx, urdevboard.brd, urdevboard.sch]
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2012-03-17 Major revision to the motor driver systems and associated cleanup.
    -JP24 renamed to JP2.
    -JP25 renamed to JP22.
    -4th encoder added. Encoders are numbered 1-4, JP24-JP27.
    -The encoders are each connected to a 4-bit port. This change makes
    the encoders compatible with the existing XMOS quadrature encoder libraries.
    -The third VNH2SP30 has been removed.
    -Added a LN298N dual 2A H-bridge as the new IC3.
    -The direction of the H-bridge motors is controlled through a shift register (IC7).
    -Added a LV8549M 1A bipolar stepper driver.
    -Reverse polarity protection circuit placed on-board.
    -IMU interrupt signals shifted to all use the same 4-bit port (X3P4A).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
    [BOM-byvalue.xlsx, signal connections.xlsx, urdevboard.brd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]
2012-03-21 SPI Ethernet controller first pass.
    -As part of this change, the package on all of the small signal diodes
    has been changed to a SOD-523. This is closer to the size of a 0402 package,
    whereas the old 0603 diodes SHOULD have been causing DRC errors on the Pmod headers.
    Space requirements for the Ethernet controller required that this be corrected ASAP.
    [BOM-byvalue.xlsx, urdevboard.brd, urdevboard.sch]
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2012-03-21 Added missing line items to BOM for ethernet controller.
    [BOM-byvalue.xlsx]
2012-03-22 Tied unused XCore 3 pins to ground to reduce EMI.
    [urdevboard.brd, urdevboard.sch]
2012-03-22 Tied unused XCore 2 pins to ground to reduce EMI.
    [urdevboard.brd, urdevboard.sch]
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2012-03-22 Fixed missing price for 200 ohm 0402 resistors.
    [BOM-byvalue.xlsx]
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2012-03-22 Pmod A traces and XSYS XLink traces first pass.
    Also made a lot of minor EMI improvements w.r.t. trace spacing/guards across the board.
    [urdevboard.brd, urdevboard.sch]
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2012-03-28 Updated J6 (RJ45 jack) to the correct package.
    [urdevboard.brd, urdevboard.sch]
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2012-03-28 Added a 100K series resistor between U24_OSC2 and GND.
    This will reduce system noise.
    [BOM-byvalue.xlsx, urdevboard.brd, urdevboard.sch]
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2012-04-13 Fixed Arduino TX/RX silk placement.
    [urdevboard.brd]
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2012-04-25 Renamed the "TOLERANCE" attributes to the standard "TOL" abbreviation.
    [urdevboard.brd, urdevboard.sch]
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
